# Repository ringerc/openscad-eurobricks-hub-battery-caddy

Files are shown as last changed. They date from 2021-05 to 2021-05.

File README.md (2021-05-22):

# 9V battery caddy for use with Lego® Powered Up!® Hub 88009

A 3D-printable 9V battery caddy compatible with Lego® Powered Up!® Hub 88009,
so you can make your motorized Lego creations rechargeable instead of throwing
away zillions of AAA batteries.

-----

**This is not a clone or duplicate of any Lego product or design. It is an
entirely original design that replaces the 6xAAA battery holder in the Lego
Powered Up hub with something more sensible.** Read this description before you
send a DMCA notice, ok?

-----

You want the file
[`lego_powered_up_battery_box_v5.stl`](lego_powered_up_battery_box_v5.stl).

Print it with the base flat on the print bed. PLA should be fine, though I used
PETG for mine. Print overhangs slowly.

See [my related blog post for
details](http://blog.ringerc.id.au/2021/05/rechargeable-lithium-ion-battery-caddy.html).

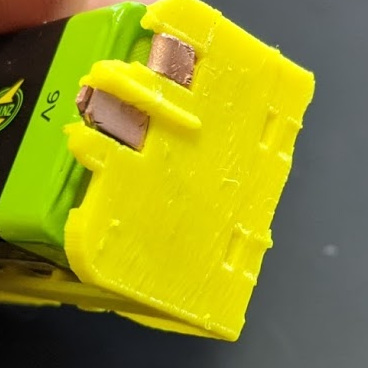
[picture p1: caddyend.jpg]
Battery caddy
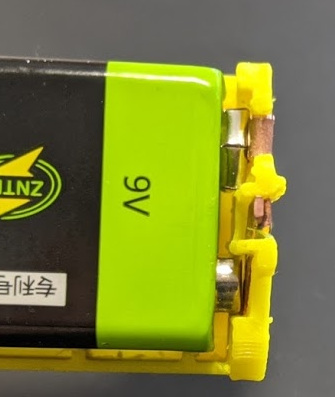
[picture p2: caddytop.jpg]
Battery caddy
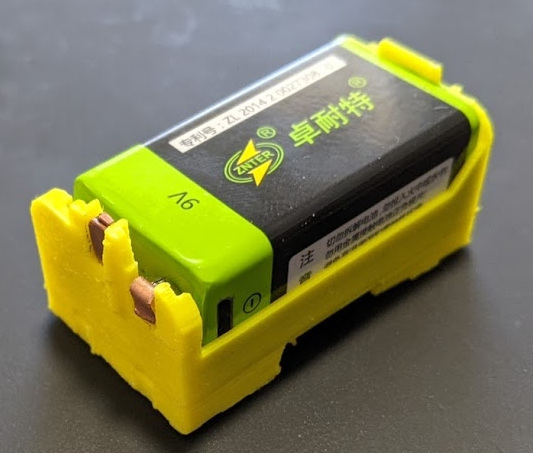
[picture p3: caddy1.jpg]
Battery caddy
  

The caddy is intended for use with 9V (PP3) form factor Li-ion USB-rechargeable
battery packs. These packs are now widely available.

Unlike traditional NiMH batteries, these packs generally continue to deliver a
steady 9V until their low-voltage cut-off trips and they shut off. So the hub
won't complain about low batteries and refuse to work as soon as the battery is
half discharged. They're convenient to recharge using a micro-USB cable. They
(should) integrate all the annoying control circiutry for charge control,
voltage buck/boost, overcharge protection, overcurrent protection, undervoltage
protection, etc. And they're fairly cheap, wheras buying the ICs or modules to
build your own is definitely not.

Enjoy. Let me know how you go.

If you're going to use the OpenSCAD sources, you'll need both my
`lego_powered_up_battery_box_v5.stl` and `roman_hegglin`'s
`uploads_f1_eb_f2_54_dd_Batteries.scad` in the same directory.

Pull requests are welcome.

## Acknowledgements

I used ["Batteries in OpenSCAD" by Thingiverse user
`roman_hegglin`](https://www.thingiverse.com/thing:155722) to supply a
convenient 9V model battery for preview and alignment purposes. I replaced my
own AAA battery model with his in the process.

[Philo](https://philohome.com/) has done tons of great write-ups on Lego stuff.
While I didn't use anything of his on this project, he was a great help in my
ongoing efforts to design an easy to make custom Powered Up compatible cable,
and my early success with driving standard hobby DC motors from the Powered Up
hub.

## Connector?

There's an OpenSCAD design in here for a connector too. It isn't very accurate
or printable yet, so ignore it.

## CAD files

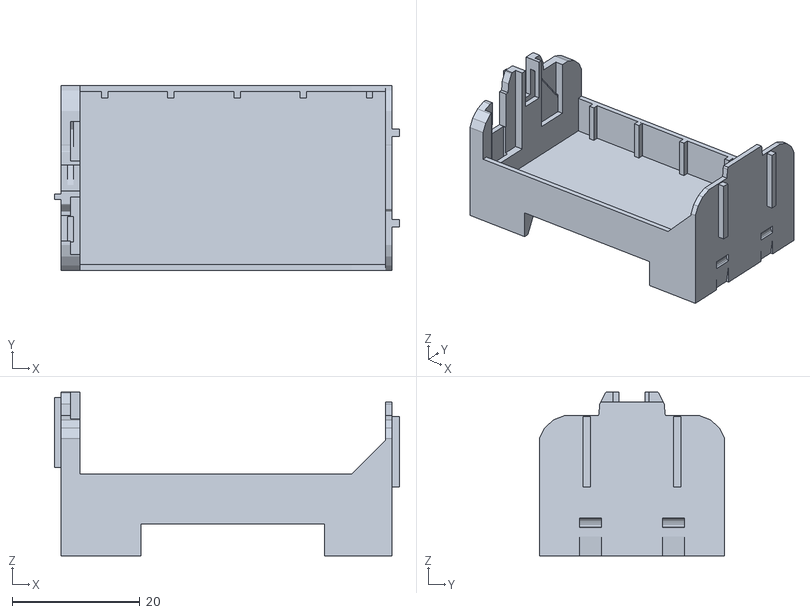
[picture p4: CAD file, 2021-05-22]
lego_powered_up_battery_box_v5.stl
54.0 x 29.0 x 25.6

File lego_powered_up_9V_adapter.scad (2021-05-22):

/*
 * 9V cell adapter for lego powered up trains. Front has contacts.
 *
 * IT WORKS!!!!!111!!!
 *
 * Slight corner rounding for printability?
 */
 
 /*
  * It's made of 6xAAAs.
  * 
  * The casing has about 0.5mm tolerance around the AAA diameter.
  */
AAA_battery_diameter = 10.5;
AAA_battery_length = 44.5;

// Space caddy allows between battery and edge of spacer, approx
battery_diameter_tolerance = 0.5;
// Z-gap between batteries in the layers
pack_battery_height_gap = 1;

end_wall_thickness_front = 3 ;
end_wall_thickness_back = 1;
end_walls_thickness_total = end_wall_thickness_front + end_wall_thickness_back;
base_thickness = 1;
side_wall_thickness = 1;

base_plate_zoff = 5;


// The entire control box case exterior is 63.8 long
base_length_outside_to_outside = 51.8;

front_height_total = 25.6;
front_width_total = 29.0;

/* Back has a cutout lower than front, seems to be part of the keying */
back_height_total = 24.1;
back_width_total = front_width_total;

clip_inset = 6.0;
clip_width = 3.5;
// Should be about 10mm between the clips
clip_gap = front_width_total - 2*(clip_inset*clip_width);
clip_height = 3;
// Gap between clip slide and notch
clip_to_notch_height = 1.0;
// How deep clip notch is. This determines the height of the notches too. They're a bit less than 2*clip_depth.
clip_depth = 0.5;
// Notch starts at +4mm, goes to +6mm, is same width as clip
notch_height = 2.0;

/* Key ridge on front is actually 12.73 high but falls on a curve. So we'll make the key shorter. */
key_ridge_front_height = 11.0; /* TODO measure */
key_ridge_front_zoff = 1;
key_ridge_front_width = 1;
key_ridge_front_depth = 0.9;
/* Its inner (left) edge is 12 - key_ridge_depth from the right edge. This offset is key ridge centre from box centre. */
key_ridge_front_yoff = -(front_width_total/2 - (12.0  - key_ridge_front_depth/2));

/* back ridges are slightly bigger */
key_ridge_back_width = 1.2;
key_ridge_back_depth = 1.2;
/* The real one follows the curve of the battery and is 14.8 high but we can just make it a bit shorter */
key_ridge_back_height = 11.0;
/* The inside of each ridge is 8mm from the corresponding edge */
key_ridge_back_yoff = back_width_total / 2 - key_ridge_back_width/2 - 8;
key_ridge_back_zoff = -2;

contact_width = 4.0;
contact_height = 7.5;
contact_depth = 4.1;

contact_positive_yoff = 0;

/* Right edge of contact cutout is 4.65 from right outside wall */
contact_negative_yoff = -(front_width_total/2 - contact_width/2) + 4.65;

contact_negative_zoff = 6; /* approx is ok here */

feet_top_d = 1.5;
feet_base_d = 3;

E=0.005;

side_wall_height = front_height_total/2;

/* Preview using AAA or 9V */
//preview_with_aaa = true;
preview_with_aaa = false;

use <uploads_f1_eb_f2_54_dd_Batteries.scad>;

module AAA_cell() {
    rotate([0,90,0])
    AAA();
};

all_batteries = ["t","b","bl","br","tl","tr"];

module batteries_AAA(which=all_batteries)
{
    let(batt_space = AAA_battery_diameter + battery_diameter_tolerance)
    for (pack_zoff = [0, AAA_battery_diameter + pack_battery_height_gap])
    translate([0,0,pack_zoff])
    {
        let(batt_name = (pack_zoff == 0 ? "b" : "t"))
        {
            //echo(pack_zoff, batt_name);
            
            if ([ for (w = which) if (w == batt_name) w])
            AAA_cell();
        }

        for (lr=[-1,1])
        let(batt_name = str((pack_zoff == 0 ? "b" : "t"), (lr == -1 ? "l" : "r")))
        {
            //echo(pack_zoff, lr, batt_name);
            
            if ([ for (w = which) if (w == batt_name) w])
            translate([0,
                lr*cos(-30)*batt_space,
                sin(-30)*batt_space])
            AAA_cell();
        }
    }
}

module batteries_9V() {
    translate([base_length_outside_to_outside,0,0])
    rotate([180,0,0])
    translate([-5,-11.5,8])
    rotate([0,-90,0])
    rotate([0,0,90])
    9V();
}

/* TODO gentle slope in bottom overhang of key items */
module key_ridge_front() {
    cube([key_ridge_front_width, key_ridge_front_depth, key_ridge_front_height]);
}

module key_ridge_back() {
    cube([key_ridge_back_width, key_ridge_back_depth, key_ridge_back_height]);
}


module contact() {
    cube([contact_depth, contact_width, contact_height], center=true);
}

module end_plate(end_plate_height, end_wall_thickness, z_offset=0) {
    let(
        pack_cube_h = 2 * AAA_battery_diameter + pack_battery_height_gap
    )
    translate([end_wall_thickness*1.5+E,0,0])
    difference() {
        union() {
            intersection() {
                translate([-end_wall_thickness,0,-2])
                {
                    hull()
                    batteries_AAA(which=[ for (w = all_batteries) if (w != "t") w ]);
                    batteries_AAA(which=["t"]);
                }

                /* main body; requires an offset for rear */
                translate([-end_wall_thickness/2,0,z_offset])
                cube([
                        end_wall_thickness,
                        front_width_total,
                        end_plate_height
                    ],
                    center=true
                );
            };
            
            /* Square off bottom */
            translate([
                -end_wall_thickness,
                -front_width_total/2,
                -end_plate_height/2 + z_offset
            ])
            cube([end_wall_thickness, front_width_total, AAA_battery_diameter], center=false);
        };
        
        /* clip notches */
        translate([-end_wall_thickness-3*E, 0, 0])
        {
            let(
                clip_curve_adj = 0.3,
                clip_cyl_r = clip_depth + clip_curve_adj
            )
            for (lr = [-1,1])
            translate([0, lr * (clip_gap/2), clip_inset])
            translate([0, 0,
                    -end_plate_height + clip_inset + z_offset])
            {
                translate([-0.3,0,0])
                translate([0,clip_width/2,-clip_cyl_r+clip_inset])
                rotate([90,0,0])
                cylinder(r=clip_cyl_r,h=clip_width,$fs=0.3);
                
                rotate([0,-8,0])
                translate([0,-clip_width/2, -clip_height])
                cube([clip_depth, clip_width, clip_height*2]);
            }
        }
    }
}

module front_plate() {
    translate([-end_wall_thickness_front/2,0,0])
    union()
    {
        difference()
        {
            end_plate(front_height_total, end_wall_thickness_front);
             
            // +ve contact (centre)
            translate([
                end_wall_thickness_front,
                contact_positive_yoff,
                front_height_total/2 - contact_height/2 + 2*E
            ])
            contact();
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

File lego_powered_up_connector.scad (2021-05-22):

/*
 * Attempt to design Powered Up-compatible power/data connector.
 */
 
 // Controls to split out the parts
 render_base = 1;
 render_clip = 1;
 // Reposition clip for printing layout
 flip_clip = 1;
 
 // Adjustment for clip fit
 clip_tolerance = -0.05;
 
 // Adjustment for clamp over conductors fit
 clampdown_top_tolerance = 0.1;
 
 
 // Contact area
 // Critical dimensions to fit the socket are:
 //
 // Edge guides: fit in slot 1mm high, 1.2mm wide
 //
 // Contact area: 3.3mm high, 7.90 wide (not inc edge guides)
 //
 // Total plug width 10.4 (7.9 + 1.2*2)
 //
 // Total plug height max 4.3 (1.0 + 3.3)
 //
 // Total plug contact area depth something appx 5.65..5.90
 //
 // Connector pitch is same as standard SATA cable: 1.27mm i.e 0.05in, or 1/2 the "standard" 2.54 or 0.10 inch pitch. Pin width is half the "standard" 0.635 mm or 0.025in, at 0.3175mm or 0.0125in.
 //
 // Note plug has some alignment features too. Small insets on sides for protrusions in socket to engage with. Small bump on end of contact area to align contacts by engaging with deepest part of socket.

contact_holder_contacts_width = 7.9;
contact_holder_edge_guide_width = 1.2;
// Therefore total width of plug is approx 10.25 or 10.30
contact_holder_total_width = contact_holder_contacts_width + contact_holder_edge_guide_width*2;

// This should add up to the contact holder thickness of 4.0mm.
// Some adjustment will be required.
contact_holder_edge_guide_height = 0.95;
contact_holder_contact_inset_height = 0.30;
contact_holder_base_height = 2.75;

contact_holder_total_height = contact_holder_edge_guide_height + contact_holder_contact_inset_height + contact_holder_base_height;

// Standard pitch, same as SATA. Separation varies with contact width, this is for flat trace style contacts. The contacts should be centered and evenly spaced. Contact height can vary a bit by the looks, the contacts are sprung on the socket end.
contact_count = 6;
contact_pitch = 1.27;
contact_width = 0.3175;
contact_height = 0.2;
contact_inset_width = contact_pitch/2;
// How far the contact grooves should extend into the handle part
contact_inset_extra_length = 2.5;

// notch placement for where contacts should slot into plug - distance from end
contact_termination_hole_length_inset = 0.3;
contact_termination_hole_length = contact_width*3;

contact_holder_length = 5.90;

// Less dimensoinally critical, the handle part
handle_length = 7.8;
handle_width = 13.9;
// z axis handle as pos above and below
handle_height_down = 0;
handle_height_up = 6.4 - contact_holder_total_height;
//handle_height_up = (6.4 - contact_holder_total_height)/2;
//handle_height_down = handle_height_up;
handle_height = handle_height_up + handle_height_down +  contact_holder_total_height;

// cable-hole area in handle
handle_cable_hole_width = contact_pitch*6;
handle_cable_hole_height = contact_pitch*2;

// side-grip notches in sides of plug
side_notch_xoff = 3.5;
side_notch_x = 0.8;
side_notch_y = 0.2;

s = 0.001;

// Plug part
module plug() {
difference()
{
    // Form a solid to cut pieces out from
    union() {
        
        // Main contact area chunk
        cube([
            contact_holder_length,
            contact_holder_total_width,
            contact_holder_total_height
            ]);
            
        // The holder part. Dimensions aren't so critical, but might as well
        // match the original.
        translate([
            -handle_length +s,
            -(handle_width - contact_holder_total_width)/2,
            -handle_height_down
        ])
        difference()
        {
            cube([
                handle_length+2*s,
                handle_width,
                handle_height
            ]);
        }
    }

    // Cut the way between the contacts on the contact area, removing the edge-guide part.
    translate([
        -s,
        -s + contact_holder_edge_guide_width,
        -s + contact_holder_base_height + contact_holder_contact_inset_height
    ])
    cube([
        contact_holder_length + 2*s,
        contact_holder_contacts_width + 2*s,
        contact_holder_edge_guide_height + 2*s
        ]);
    
    // In the main contacts area, cut inset grooves for the contacts to ride in. These can be customised. They deliberately extend into the handle-part.
    let(contact_edge_inset = (contact_holder_contacts_width - (6*contact_pitch))/2)
    translate([0, contact_holder_edge_guide_width + contact_edge_inset, 0])
    {
        // Main contacts area
        for (c = [1 : 6]) {
            // Pitch is the critical factor in contact placement.  At a pitch of 1.27mm, the width is 7.62mm. The measured 7.9 is because there are lips on the edges. Place contacts from center out. This is the cutouts.
            // This both makes the wire channels in the front and the holes for the conductors in the back plug cutout.
            translate([0, (contact_pitch - contact_inset_width)/2, 0])
            {
                translate([
                    -s - contact_inset_extra_length,
                    (c-1)*contact_pitch
                    ,contact_holder_base_height
                ])
                cube([
                    contact_holder_length + contact_inset_extra_length+s*2,
                    contact_inset_width,
                    contact_holder_contact_inset_height
                    ]);
            }
        }
    }
    
    // Cut out the cable space in the plug connector, not including the individual
    // conductor channel holes.
    translate([
        -s - handle_length,
        abs(handle_cable_hole_width-contact_holder_total_width)/2,
        (contact_holder_base_height+contact_holder_contact_inset_height)/2
    ])
    cube([
        handle_length - contact_inset_extra_length + s,
        handle_cable_hole_width,
        handle_cable_hole_height
    ]);
    
    // Cut out the notches for the side grips to engage.
    for (i = [0,1])
    translate([
        side_notch_xoff,
        -s + i*(contact_holder_total_width-side_notch_y),
        -s
    ])
    cube([
        side_notch_x,
        side_notch_y+2*s,
        contact_holder_total_height+2*s
    ]);
        
}
}

// Support cutting out a separate clip in the handle
//
// The clip tolerance should be +ve for the clip and negative when used as a mask. It affects the clip tooth size and clip width and length.
module plug_clamp(clip_tolerance, clampdown_top_tolerance) {
union()
{
    // lid of clip
    translate([
        -handle_length -s,
        -s -(handle_width - contact_holder_total_width)/2,
        contact_holder_total_height-s
    ])
    difference()
    {
        cube([
            handle_length+6*s,
            handle_width+2*s,
            handle_height_up + 2*s
        ]);
    }
 
    // Clampdown area over contacts
    let(clampdown_side_tolerance = -0.6)
    translate([
        -s - contact_inset_extra_length,
        -s + contact_holder_edge_guide_width - clampdown_side_tolerance/2,
        -s + contact_holder_base_height + contact_holder_contact_inset_height - clampdown_top_tolerance
    ])
    cube([
        contact_inset_extra_length + 2*s,
        contact_holder_contacts_width + 2*s + clampdown_side_tolerance,
        contact_holder_edge_guide_height + clampdown_top_tolerance + 2*s
        ]);
    
    // cutouts in sides for clips
    let(
        clip_length = handle_length/2 + clip_tolerance,
        clip_width = (handle_width - contact_holder_total_width)/4 + clip_tolerance,
        clip_height = contact_holder_total_height * 0.75,
        clip_tooth_length = clip_width/2,
        clip_tooth_width = clip_width/2
    )
    translate([
        -handle_length * 0.75 - clip_tolerance/2,
        0,
        contact_holder_total_height - clip_height - clip_tolerance/2
    ])
    {
        translate([0, -(handle_width - contact_holder_total_width)/2 - s, 0])
        {
            cube([clip_length, clip_width, clip_height + abs(clip_tolerance)]);
        
            translate([0, clip_width - s, 0])
            cube([clip_length, clip_tooth_length + s, clip_tooth_width + clip_tolerance/2]);
        }
        
        translate([0, handle_width/2 + contact_holder_total_width/2 - clip_width + s, 0])
        {
            cube([clip_length, clip_width, clip_height + abs(clip_tolerance)]);
            
            translate([0, -clip_tooth_length - s, 0])
            cube([clip_length, clip_tooth_length + 2* s, clip_tooth_width]);
        }
    }
}
}

module plug_base(clip_tolerance) {
    difference() {
        plug();
        plug_clamp(-clip_tolerance, 0);
    }
}


if (render_base)
translate([0,0,handle_height_down])
plug_base(clip_tolerance);
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

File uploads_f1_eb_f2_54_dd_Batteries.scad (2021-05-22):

/*
 * "Batteries in OpenSCAD by roman_hegglin"
 * https://www.thingiverse.com/thing:155722
 */
/*$fn=70;*/

AA();
translate( v=[15,0,0])
AAA();
translate( v=[35,0,0])
C();
translate( v=[68,0,0])
D();
translate( v=[90,-0.5*(17.5-2*2),0])
9V();
translate( v=[130,0,0])
45V();


module AA()
{
battery_round(50.5, 14.5, 1.0, 5.5);
}

module AAA()
{
battery_round(44.5, 10.5, 0.8, 3.8);
}

module C()
{
battery_round(50, 26.2, 1.5, 7.5);
}

module D()
{
battery_round(61.5, 34.2, 1.5, 9.5);
}

module 9V()
{
r=2;
union(){
	translate(v = [(26.5-2*r)/2-12.95/2, (17.5-2*r)/2, 46.4]) {
		cylinder(h = 48.5-46.4, r=3);
	}

	translate(v = [(26.5-2*r)/2+12.95/2, (17.5-2*r)/2, 46.4]) {
		for ( i = [0:3])
			{ rotate ( i * 60, [0,0,1])
				cube([7.79,4.5,(48.5-46.4)*2],center = true);
			}
		
	}

	minkowski()
	{
	 cube([26.5-2*r,17.5-2*r,46.4/2]);
	 cylinder(r=r,h=46.4/2);
}
}
}

module 45V()
{
h=67;
w=22;
l=62;



minkowski()
{
 cube([l-w/2,0.1,h/2]);
 cylinder(r=w/2,h=h/2);
}

}

module battery_round(h, dia, h_con, dia_con)
{
union() {
	cylinder(h = h-h_con, r=dia/2);
	translate(v = [0, 0, h-h_con]) {
		cylinder(h = h_con, r=dia_con/2);
	}
}
}

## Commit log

2021-05-22 model of powered up connector, draft
    [lego_powered_up_connector.scad]
2021-05-22 basic design done, printability?
    [lego_powered_up_connector.scad]
2021-05-22 should be ready to try
    I suspect I'll want to print in two parts and make it crimpable
    later, but this'll do for fit checking.
    [lego_powered_up_connector.scad]
2021-05-22 connector v2
    [lego_powered_up_9V_adapter.scad, lego_powered_up_connector_v2.stl]
2021-05-22 Back-slope connector sockets and widen holes
    [lego_powered_up_connector.scad]
2021-05-22 wip plug clamp separation
    [lego_powered_up_connector.scad]
2021-05-22 Connector v3, printed clip style
    [lego_powered_up_connector.scad, lego_powered_up_connector_v3.stl]
2021-05-22 v4 with clip adjustments
    [lego_powered_up_connector.scad, lego_powered_up_connector_v4.stl]
2021-05-22 cutouts around batt
    [lego_powered_up_9V_adapter.scad]
2021-05-22 Revert "cutouts around batt"
    This reverts commit ea0cec45cf63d1924bd007ae0637e3f88cdfbdd2.
    [lego_powered_up_9V_adapter.scad]
2021-05-22 battery compartment
    [lego_powered_up_9V_adapter.scad]
2021-05-22 wip with 9v
    [lego_powered_up_9V_adapter.scad, uploads_f1_eb_f2_54_dd_Batteries.scad]
2021-05-22 standoff feet for batt
    [lego_powered_up_9V_adapter.scad]
2021-05-22 fix manifold
    [lego_powered_up_9V_adapter.scad]
2021-05-22 fix length
    [lego_powered_up_9V_adapter.scad]
2021-05-22 Some fixes for geom
    [lego_powered_up_9V_adapter.scad]
2021-05-22 Make it work
    [lego_powered_up_9V_adapter.scad]
2021-05-22 Battery box v1
    [lego_powered_up_9V_adapter.scad, lego_powered_up_battery_box_v1.stl]
2021-05-22 raise base plate
    [lego_powered_up_9V_adapter.scad]
2021-05-22 side pushers for batt
    [lego_powered_up_9V_adapter.scad]
2021-05-22 keying v1
    [lego_powered_up_9V_adapter.scad]
2021-05-22 contact retainers
    [lego_powered_up_9V_adapter.scad]
2021-05-22 wip endcap improvement
    [lego_powered_up_9V_adapter.scad]
2021-05-22 v4
    pretty good now.
    need to reinforce the sidewalls at the bottom
    and remove the center between the cutout arcs entirely
    [lego_powered_up_9V_adapter.scad]
2021-05-22 side cutouts
    [lego_powered_up_9V_adapter.scad]
2021-05-22 Remove v1 STL
    [lego_powered_up_9V_adapter.scad, lego_powered_up_battery_box_v1.stl]
2021-05-22 Add v5 STL
    [lego_powered_up_battery_box_v5.stl]
2021-05-22 Remove connector STLs
    [lego_powered_up_connector_v1.stl, lego_powered_up_connector_v2.stl, lego_powered_up_connector_v3.stl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]
2021-05-22 Document connector
